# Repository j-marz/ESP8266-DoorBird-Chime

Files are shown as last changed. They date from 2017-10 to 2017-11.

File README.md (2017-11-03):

# ESP8266-DoorBird-Chime
WiFi doorbell chime using a NodeMCU ESP8266 devboard for use with DoorBird smart doorbell.

A low cost (<$15AUD) alternative to the DoorBird IP Door Chime A1061W ~$250AUD

## Parts
* NodeMCU ESP8266 dev board ~$6AUD - https://www.ebay.com.au/itm/162194307584
* Passive buzzer module ~$3AUD - http://www.ebay.com.au/itm/282263010801
* Jumper wires (female-to-female) ~$3AUD - http://www.ebay.com.au/itm/40pcs-10cm-Dupont-Cables-F-F-Jumper-Breadboard-Wire-GPIO-Ribbon-Pi-Arduino-New/122343723749
* Micro USB 5 volt power supply - ~$5AUD - an old phone charger will work or connect directly to USB port of computer

## Instructions
1. Add your SSID and WPA(2) passphrase to the sketch - ssid and password variables
2. Use Arduino IDE to upload sketch to the ESP8266
3. Connect the buzzer module to the GPIO pins using jumper wires - GND to G, VCC to 3V, I/O to D1
4. Configure the DoorBird's notification event API to call the web service on the ESP8266 - you will be promted to enter the DoorBird's username and password
`http://<IP address of your DoorBird>/bha-api/notification.cgi?url=http://<IP address of your ESP8266>/chime=dingDong/&event=doorbell&subscribe=1`

See DoorBird's API documentation for more info - https://www.doorbird.com/downloads/api_lan.pdf?rev=0.17

Note, you'll need to find the IP address of your DoorBird and the ESP8266 device from your DHCP server or router.

## Testing
You can test the chime directly using your web browser
`http://<IP address of your ESP8266>/`

Click on the chime options
* `dingDong` Ding Dong tone + LED
* `silent` 20 LED flashes over 10 seconds

## Enclosure/case
I've included STL files of a 3D printed case i designed for the specific NodeMCU devboard listed above. The case may not be suitable for all NodeMCU variants (e.g. Amica)
* Speaker hole and mount point on rear lid
* Hole for onboard LED on front
* Holes for Devboard buttons on front

## To Do
* Add authentication to the web service
* Add more chime options

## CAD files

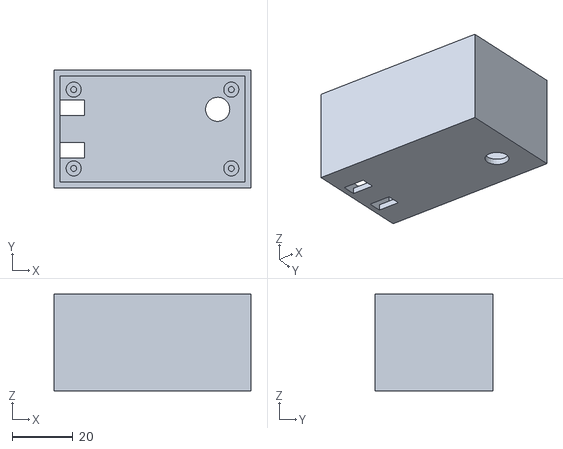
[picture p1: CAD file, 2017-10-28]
nodemcu_case_main.stl
65.0 x 39.0 x 32.0

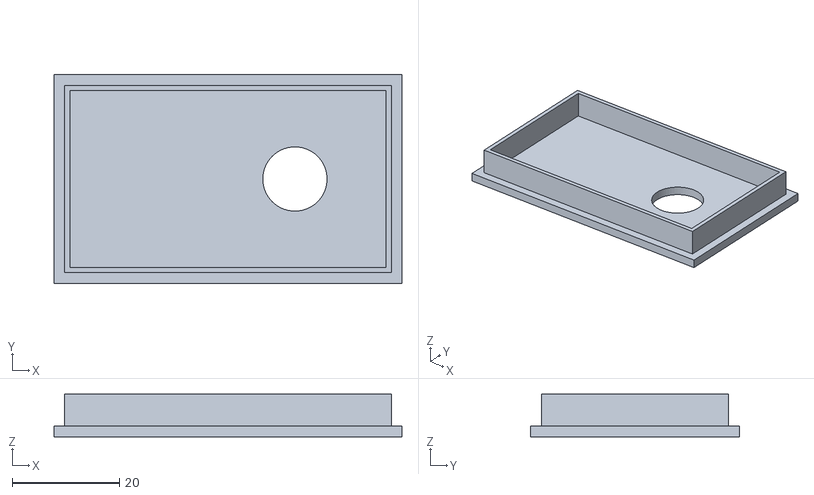
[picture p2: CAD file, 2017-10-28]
nodemcu_case_lid.stl
65.0 x 39.0 x 8.00

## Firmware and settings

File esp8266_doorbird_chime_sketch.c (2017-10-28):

/***************************
 ESP8266 DoorBird Chime
 ----------------------
 Created by: John Marzella
 Created on: 29/09/2017
***************************/

#include <ESP8266WiFi.h>
 
const char* ssid = "";// type your SSID
const char* password = "";// type your WPA(2) passphrase
const char* netname = "ESP8266-DoorBird-Chime";// type your network hostname
 
int ledPin = 2; // GPIO2 of ESP8266 - onboard LED
int buzzPin = 5; // GPIO2 of ESP8266 - NodeMCU pin D1

WiFiServer server(80); //Service Port
 
void setup() {
  Serial.begin(115200);
  delay(10);
 
  pinMode(ledPin, OUTPUT);
  digitalWrite(ledPin, HIGH); // LED off on startup
   
  // Connect to WiFi network
  Serial.println();

  Serial.println("Set WiFi to STAtion mode");
  WiFi.mode(WIFI_STA);

  Serial.print("Set hostname to: ");
  Serial.println(netname);
  WiFi.hostname(netname);

  Serial.print("Connecting to SSID: ");
  Serial.println(ssid);
  WiFi.begin(ssid, password);
   
  while (WiFi.status() != WL_CONNECTED) {
    delay(500);
    Serial.print(".");
  }
  Serial.println("");
  Serial.println("WiFi connected");
   
  // Start the server
  server.begin();
  Serial.println("Server started");
 
  // Print the IP address
  Serial.print("Use this URL to connect: ");
  Serial.print("http://");
  Serial.print(WiFi.localIP());
  Serial.println("/");
}
 
void loop() {
  // Check if a client has connected
  WiFiClient client = server.available();
  if (!client) {
    return;
  }
   
  // Wait until the client sends some data
  Serial.print("New client connected: ");
  Serial.println(client.remoteIP().toString().c_str());
  while(!client.available()){
    delay(1);
  }
   
  // Read the first line of the request
  String request = client.readStringUntil('\r');
  Serial.println(request);
  client.flush();
   
  // Match the request
  if (request.indexOf("/chime=dingDong/") != -1) { // Ding Dong chime + LED
    digitalWrite(ledPin, LOW);
    tone(buzzPin,370);//370Hz aka F#4
    delay(1000);
    tone(buzzPin,294);//294Hz aka D4
    delay(2000);
    noTone(buzzPin);// stop tone
    digitalWrite(ledPin, HIGH);
    delay(1000);
    digitalWrite(ledPin, LOW);
    tone(buzzPin,370);//370Hz aka F#4
    delay(1000);
    tone(buzzPin,294);//294Hz aka D4
    delay(2000);
    noTone(buzzPin);// stop tone
    digitalWrite(ledPin, HIGH);
    delay(100);
  }
  if (request.indexOf("/chime=silent/") != -1){ // Flashing LED - 20 times
    for (int counter=1; counter<=20; counter = counter+1) {
      digitalWrite(ledPin, LOW);
      delay(500);// delay 500ms
      digitalWrite(ledPin, HIGH);
      delay(500);// delay 500ms
    }
  }
 
  // Return the response
  client.println("HTTP/1.1 200 OK");
  client.println("Content-Type: text/html");
  client.println(""); //  do not forget this one
  client.println("<!DOCTYPE HTML>");
  client.println("<html>");
  client.println("<h1>ESP8266 DoorBird Chime</h1>");
  client.println("<h3>Options:</h3>");
  client.println("<a href=\"/chime=dingDong/\">dingDong</a> Ding Dong tone + LED<br>");
  client.println("<a href=\"/chime=silent/\">silent</a> 20 LED flashes over 10 seconds<br>");
  client.println("</html>");

  // Close the client connection
  delay(1);
  client.stop();
  Serial.println("Client disconnected");
  Serial.println("");
}
